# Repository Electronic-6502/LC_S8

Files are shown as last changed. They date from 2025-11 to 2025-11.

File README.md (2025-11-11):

# What is this ?
LC_S8 is a Open Source LC meter
can Measure Frequency, Capacitance (and ESR) and Inductance

# 3D PreView
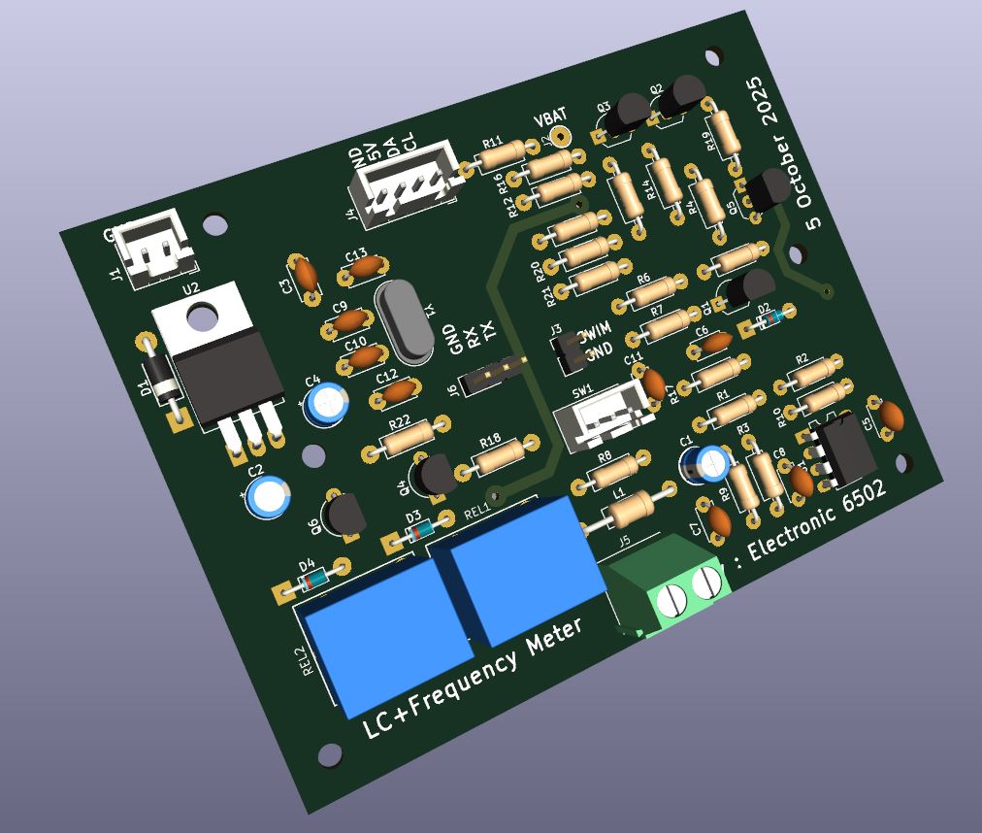
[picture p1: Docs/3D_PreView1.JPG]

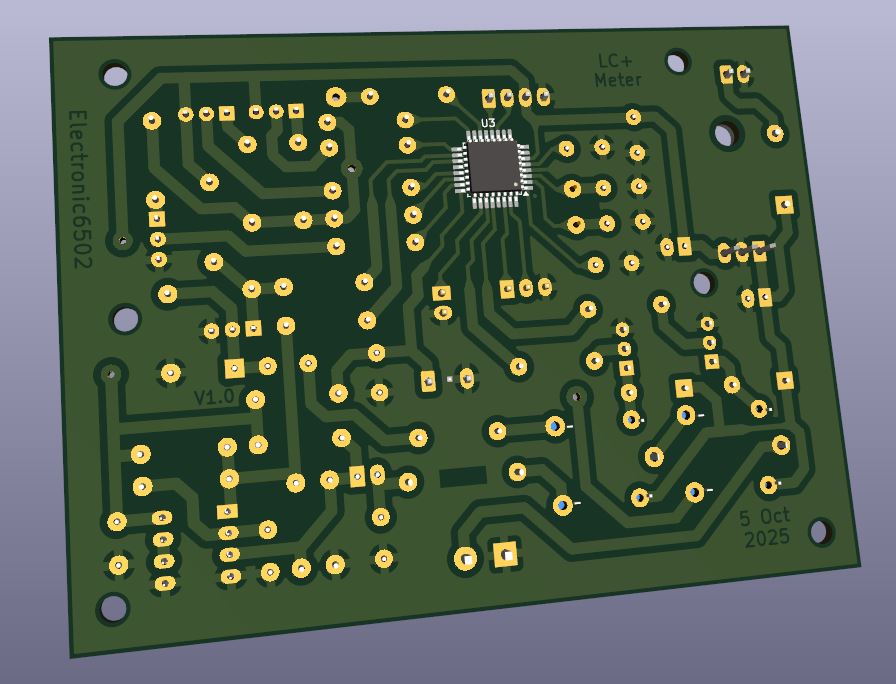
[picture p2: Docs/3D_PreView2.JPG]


# Specifications
 ## Power Supply
 - Voltage : 9-12V (9V Recommended)
 - Current : 150mA Max

 ## Frequency Meter :
 - Frequency Range : 2Hz - 8MHz
 - Resolution : 1Hz for F<10kHz and 0.01kHz for F>=10kHz
 - Tolerence : 0.1% Max
 - minimum Signal Amplitude : 0.2Vrms for F>50Hz and 1Vrms for F<=50Hz
 - Maximum Amplitude : 50Vpp

 ## Capacitance Meter :
 - Capacitance Range : 5pF to 50mF
 - Tolerence : 5% Max
 - ESR Range : 0.01Ω to 100Ω
 - Measure Stand-Alone Resistor : YES
 - Injected Input Voltage Range : -6V to +6V

 ## Inductance Meter 
 - Inductance Range : 0.01uH to 999H
 - Tolerence : 5% Max (NOT Guaranted !)

# File Structure 
 ## Docs
  misc Documents Like Components List (now only in Persian Language)

 ## Source
  Source Code with Libraries in C Language
 
 ## Hardware
  Schematic and PCB Files
 
 ## HEX_Build
  Ready-to-Program HEX File for Microcontroller

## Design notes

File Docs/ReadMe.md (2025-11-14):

There are 3 XH connector and 1 KF128 terminal on the PCB.
J1 (KF128) is used for power supply. It is suggested to use Litium-ion battery with a boost converter for power supply. Using adapter for power supply, could lead to instability in measuring capacitance operation.
`J4` connector is connected to `PCF8574` module (in the back 1602 LCD). Name of each pin is written beside.
`SW1` connector, connects to the push button. Important notice is middle pin is not used and it should be removed (with a plier) from male connector.
`J5` terminal is connected to measuring probes.

# usage, calibration and first uses

This PCB have 3 modes for measuring:
- Frequency
- Capacitance
- Inductor

After turn on, the deafult mode is Frequency meter. with pressing button, it will go to next mode (Capacitor) and with another press it will go to next (Inductance) and this cycle will will continue.
If in either Capacitor or Inductor mode, if the button is hold for some seconds, PCB goes into calibration mode.

## Calibrating Capacitor Meter
Put the PCB into Capacitance mode. Press and hold the button for some seconds. When LCD is wiped out, you can release the button. the message `Short Probes and Press Button` will appear on the LCD which you should short-circuit the measuring probes and then press the button.
then `Open Probes and Press Button` message will appear which you have to separate the probes and press the buttom again. then the message `Calibration Success` is shown and it means the successfull calibration.

## Calibrating Inductor Meter
Put the PCB into Capacitance mode and short circuit the probes.
Then press and hold the button, untill the message `Calibrated` is shown which means successfully calibrated.

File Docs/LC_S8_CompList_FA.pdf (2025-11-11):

لیست قطعات پروژه LC متر
LC-S8
بروزرسانی : 20 آبان 1404

مقاومت ها:
مرجع مقدار توان تعداد
اهم 100 R15, R19

1/4 وات
)0.25W(

2
3 | 1K | R2, R6, R7 R12, R18, R21, R22
4 | 4.7K
R1, 3, 4, 8, 9, 11,
13, 14, 16, 17
10 | 10K
3 | 1M | R5, R10, R20

خازن ها :
مرجع ظرفیت ولتاژ نوع تعداد
2 | | عدسی | | 25-50V | 15-20pF | C9, C10
1 | MKT-NP0-C0G 50-250V | 4.7nF | C7
2 | الیر | مولتی- | عدسی | 25-50V | 10nF | C11, C12
4 | الیر | مولتی- | عدسی | 25-50V | 100nF | C3, C5, C6, C8
13C uF1 V25-50 عدسی-مولتی الیر 1
1 | الکترولیت | 25-63V | 10uF | C1
2 | پلیمری | - | الکترولیت | 16-25V | 100uF | C2, C4

سلف :
مرجع مقدار توان نوع تعداد
1 | Axial- | مقاومتی | 0.5-1W | 100uH | L1
| | | | page 1/2

دیود ها :
مرجع مدل / نام تعداد
1 | 1N5817 - 1N5819 | D1
3 | 1N4148 | D2, D3, D4
| ترانزیستور ها:
مرجع مدل / نام تعداد
1 | BC547 | Q1
1 | BC557 | Q2
1 | BC327 | Q3
3 | BC337 | Q4, Q5, Q6

آیسی و میکروکنترلر ها:
مرجع مدل / نام تعداد
1 | LM393 - KA393 | U1
1 | 7805 | U2
| | U3

STM8S003K3
or
STM8S103K3

1

سایر :
مرجع نام قطعه تعداد
1 | 2x16 | کاراکتری | LCD | -
- ماژول 8574PCF 1
2REL 1,REL رله 12 ولت پکیج 78T( بچه میلون( 2 1SW شستی فشاری 1
کانکتور XH نری 2و3و4 پین به همراه مادگی سیم دار، هر کدام 1 عدد

نکته : قطعاتی که با رنگ سبز مشخص شده اند ، به معنی توصیه شده با عملکرد / طول عمر بهتر هستند.

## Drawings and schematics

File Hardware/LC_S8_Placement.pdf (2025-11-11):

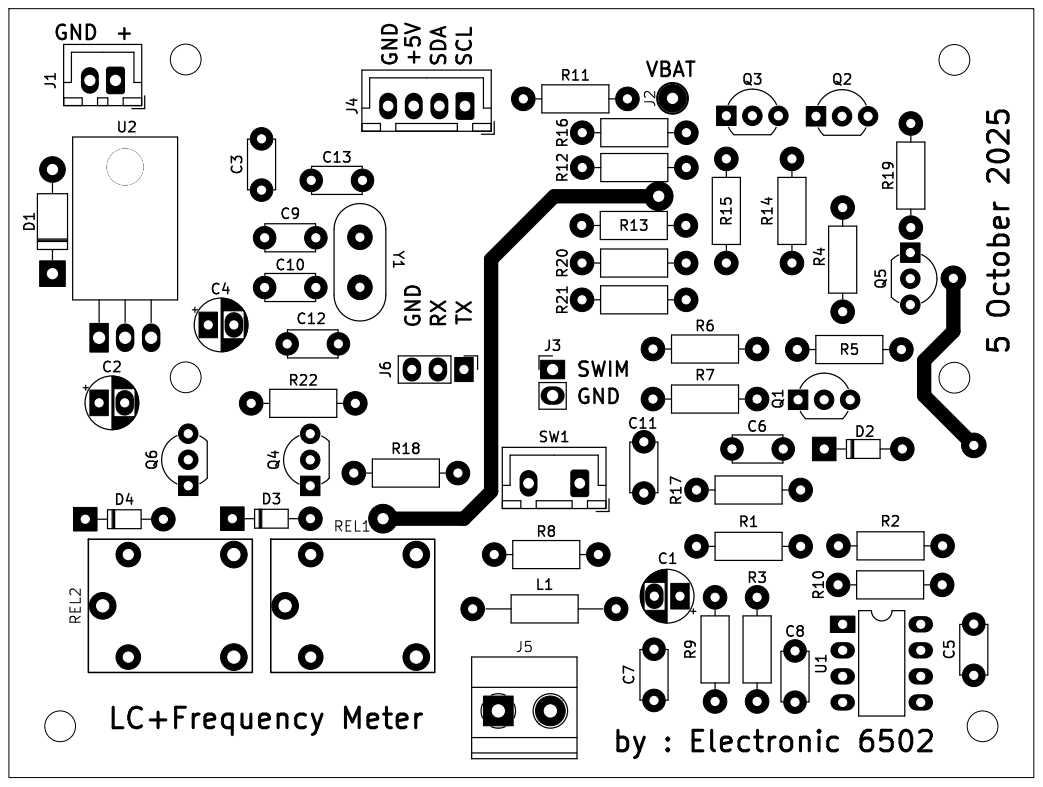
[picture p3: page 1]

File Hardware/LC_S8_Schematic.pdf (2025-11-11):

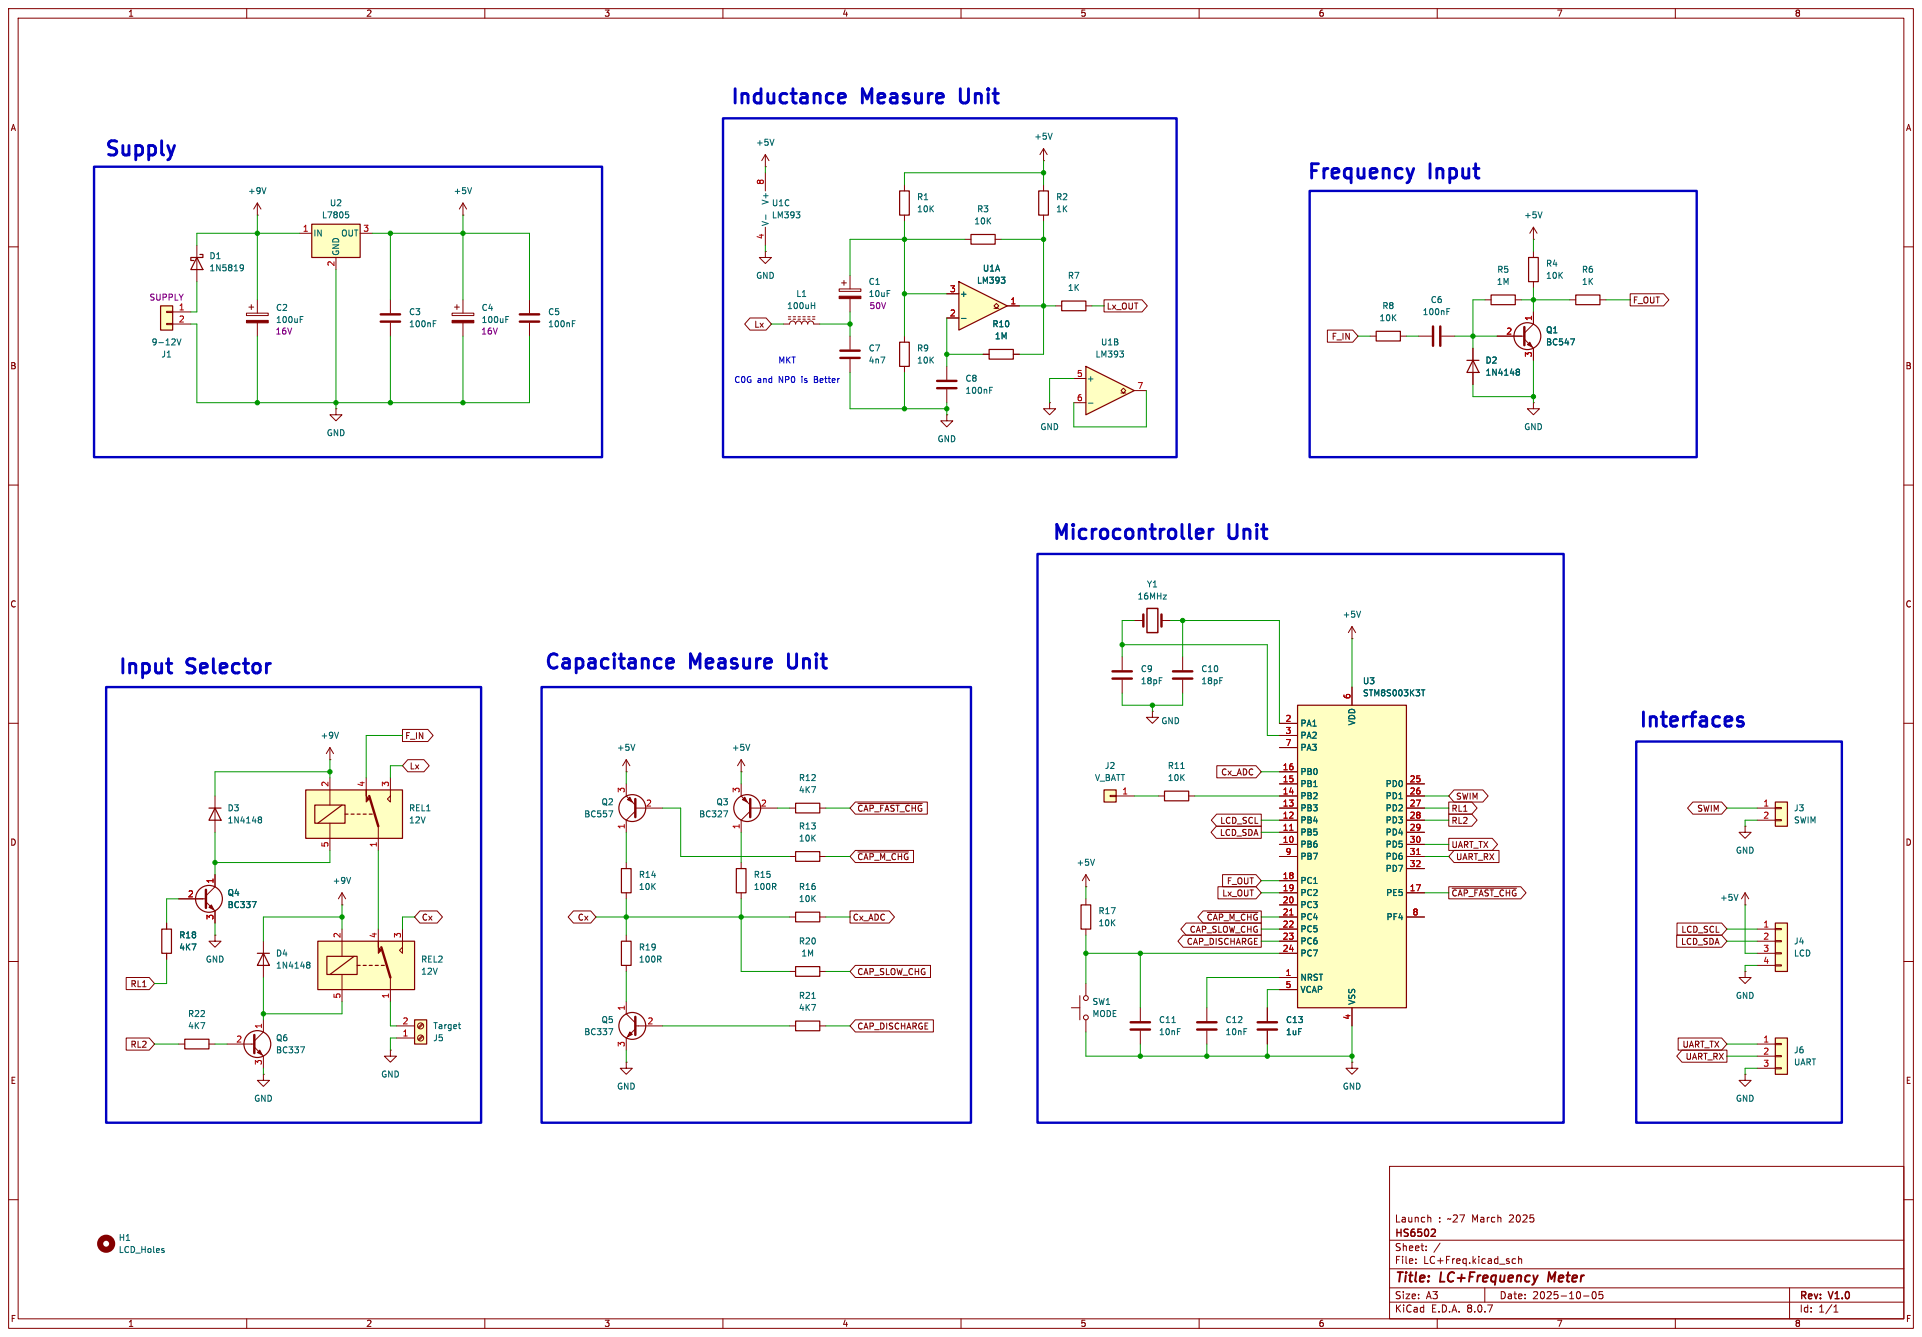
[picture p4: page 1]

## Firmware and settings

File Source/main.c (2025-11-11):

/**
 * @file    main.c
 * @author  Electronic6502
 * @version V1.0
 * @date    8 Oct 2025
 * @brief   LCR1 Source File
 */
/* Toolchain : SDCC */
#include <string.h>
#include "3rd_Lib/stm8s.h"
#include "periph_and_misc.h"
#include "LCD_1602.h"

#define VERSION         "V1.0"

#define C9_CAP_VAL      0.0000000047f          /* Value of C9 on PCB in Farad */ // 4.45nf mog

#define R19_L_VAL       1000000.0f              /* Capacitor Charge Resistors */
#define R12_M_VAL       10000.0f
#define R13_H_VAL       100.0f

uint8_t Crystal_Error_Flag = 0;
uint8_t Unit_String [4];
const uint8_t Empty[] = {"          "};         /* 10x Empty Character */
volatile uint8_t GotoNextMode = 0;
volatile uint8_t Button_Hold_Cnt = 0;
volatile uint16_t TIM1_OVF_Count = 0;
volatile uint16_t TIM2_OVF_Count = 0;

void Boot_Messages (void){
    static float VBAT;
    LCD_GotoXY (5,0);
    LCD_PutString ("LC-S8\n");
    LCD_GotoXY (5,1);
    LCD_PutString (VERSION);
    Delay_ms (2000);
    LCD_Clear ();
    LCD_GotoXY (6,0);
    LCD_PutString ("by:\n Electronic-6502");
    Delay_ms (2000);
    LCD_Clear ();
    LCD_PutString ("Battery Voltage\n");
    VBAT = (ADC_Read(VBAT_ADC) / 1023.0f) * 5.0f;       /* Read Battery Voltage */
    Print_Float (VBAT);
    LCD_PutChar ('V');
    Delay_ms (1800);
    if (Crystal_Error_Flag){
        LCD_Clear ();
        LCD_GotoXY (4,0);
        LCD_PutString ("Warning! \n Crystal Error!");
        Delay_ms (5000);
    }
    LCD_Clear ();
}

void ModeConfig (uint8_t Mode){
    Delay_ms (150);                                             /* Delay Needed to Debouncing Button */
    GotoNextMode = 0;
    LCD_Clear ();
    if (Mode == MODE_Frequency){   
        PinLow (REL_PORT, REL1_PIN);                            /* Switch Relay1 to NC */
        PinLow (REL_PORT, REL2_PIN);                            /* Switch Relay2 to NC */
        LCD_PutString ("Frequency:");
    }
    else if (Mode == MODE_Capacitance){
        PinHigh (REL_PORT, REL2_PIN);                           /* Switch Relay2 to NO */
        LCD_PutString ("CAP:"); 
        LCD_GotoXY (0,1);                                       /* Goto Next Line */
        LCD_PutString ("ESR:");                                   
    }
    else {                                                      /* Inductance Meter */
        PinLow (REL_PORT, REL2_PIN);
        PinHigh (REL_PORT, REL1_PIN);                           /* Switch Relay1 to NO */
        LCD_PutString ("Inductance:");
    }
    TIM1_Config_for (Mode);
}

void FrequencyMeter (void){
    float Freq;
    ModeConfig (MODE_Frequency);
    while (GotoNextMode == 0){
        Freq = TIM1_PulseCounter (1000);
        LCD_GotoXY (0,1); 
        LCD_PutString (Empty);
        LCD_GotoXY (0,1);
        if (Freq < 10000.0f){
            strcpy (Unit_String, "Hz");
            Print_Number (Freq);
        } 
        else{
            strcpy (Unit_String, "kHz");
            Freq /= 1000.0f;
            Print_Float (Freq);
        }
        LCD_PutString (Unit_String);
    }
}

void Capacitor_Discharge (void){
    PinHigh (CAP_PORT, CAP_DISCHG_PIN);
    while (ADC_Read(CAP_ADC) > 1);                         /* Wait for Discharge Capacitor */
    Delay_ms (10);
    PinLow (CAP_PORT, CAP_DISCHG_PIN);    
}

uint8_t Calibrate = 0;
    
float Measure_ESR (void){
    uint16_t ADC_Val, i;
    float ESR, ESR_ZERO, Volt, DurPulse, AfterPulse;        /* ESR Meter Variables */
    ESR_ZERO = EEPROM_Read_Float (EEP_ESR_ZERO_ADDR);    
    AfterPulse = 0.0f;
    DurPulse   = 0.0f;
    PinOutput (CAP_PORT, CAP_CHG_LOW_PIN);
    PinLow (CAP_PORT, CAP_CHG_LOW_PIN);                 /* Pull Down ADC with 1MΩ Resistor */
    for (i=0; i<256; i++){
        PinHigh (CAP_PORT, CAP_DISCHG_PIN);             /* Discharge Capacitor */
        Delay_us (600);
        PinLow (CAP_PORT, CAP_DISCHG_PIN);              /* Stop Discharging */        
        PinLow (CAP_HIGH_PORT, CAP_CHG_HIGH_PIN);       /* Start 50mA Pulse */
        //Delay_us (2);
        ADC_Val = ADC_Read (CAP_ADC);                   /* Read ADC During Pulse */
        PinHigh (CAP_HIGH_PORT, CAP_CHG_HIGH_PIN);      /* Stop 50mA Pulse */
        DurPulse += ADC_Val;
        Delay_us (50);                                  /* wait for Overhead Voltage drop */
        AfterPulse += ADC_Read (CAP_ADC);
    }
    PinInput (CAP_PORT, CAP_CHG_LOW_PIN);               /* Disable Pull Down */
    DurPulse = DurPulse - AfterPulse;
    Volt = (VREF * DurPulse) / 261888.0f;               /* Measure Voltage */
    ESR = R13_H_VAL / ((VREF / Volt) - 1.0f);
    if (Calibrate){
        ESR_ZERO = ESR;
        EEPROM_Save_Float (ESR_ZERO, EEP_ESR_ZERO_ADDR);
        LCD_Clear ();
        LCD_PutString ("Open Probes and\n Press Button");
        while (ReadPin (BUTTON_PORT, BUTTON_PIN));
        Delay_ms (500);
    }
    ESR = (ESR - ESR_ZERO) - 0.05f;       /* ESR minus Offset Resistance and Capacitor Charge Voltage */
    return ESR;
}

void CapacitorMeter (void){
    static float CAP, CAP_ZERO, ChargeTime, ESR;
    CAP_ZERO = EEPROM_Read_Float (EEP_CAP_ZERO_ADDR);
    RESTART_CAP_METER :
    ModeConfig (MODE_Capacitance);    
    while (GotoNextMode == 0){
        Capacitor_Discharge ();
        if (ReadPin(BUTTON_PORT, BUTTON_PIN) == 0){
            Button_Hold_Cnt++;
            if(Button_Hold_Cnt > 5) Calibrate = 1;
        }
        if (Calibrate){
            LCD_Clear ();
            while (ReadPin (BUTTON_PORT, BUTTON_PIN) == 0); /* Wait for Button Release */
            LCD_PutString ("Short Probes and\n Press Button");
            Delay_ms (500);
            while (ReadPin (BUTTON_PORT, BUTTON_PIN));      /* Wait for Press Button */
            Delay_ms (500);
        }
        CAP = 0.0f;
        ADC_Config ();                                      /* ADC in Single Conversion Mode */
        ESR = Measure_ESR ();
        ADC1->CR1 |= ADC1_CR1_CONT;                         /* ADC in Continuous Conversion Mode */
        ADC1->CR1 |= ADC1_CR1_ADON;                         /* Start ADC Conversion */
        TIM1_ResetCounter ();
        PinLow (CAP_HIGH_PORT, CAP_CHG_HIGH_PIN);     /* Charge Capacitor with ~50mA (for Short Check) */
        Delay_ms (50);
        PinHigh (CAP_HIGH_PORT, CAP_CHG_HIGH_PIN);          /* Stop Charging */
        Delay_ms (1);
        if (ADC_Read_CONT() > 1){                        /* Capacitor have Voltage, Not Shorted */
            Capacitor_Discharge ();
            PinLow (CAP_HIGH_PORT, CAP_CHG_HIGH_PIN);
            TIM1->CR1 |= TIM1_CR1_CEN;                          /* Enable Counter */
            while (ADC_Read_CONT() < 646);
            TIM1->CR1 &= ~TIM1_CR1_CEN;                         /* Disable Counter */
            PinHigh (CAP_HIGH_PORT, CAP_CHG_HIGH_PIN);
            ChargeTime = TIM1_ReadCount();                      /* Read Capacitor RC Time in uS */
            CAP = (ChargeTime / R13_H_VAL);                     /* Measure Capacitance in uF */               

            if (ChargeTime < 3000.0f){                          /* Capacitor between 300nF and 30uF */
                TIM1_ResetCounter ();
                Capacitor_Discharge ();
                PinLow (CAP_PORT, CAP_CHG_MED_PIN);             /* Charge Capacitor with ~500uA */
                TIM1->CR1 |= TIM1_CR1_CEN;
                while (ADC_Read_CONT() < 646);
                TIM1->CR1 &= ~TIM1_CR1_CEN;
                PinHigh (CAP_PORT, CAP_CHG_MED_PIN);    
                ChargeTime = TIM1_ReadCount(); 
                CAP = (ChargeTime / R12_M_VAL);                 /* Measure Capacitance in uF */           
            }           
            if (ChargeTime < 3000.0f){                          /* Capacitor Smaller than 300nF */
                TIM1_ResetCounter ();
                Capacitor_Discharge ();
                PinOutput (CAP_PORT, CAP_CHG_LOW_PIN);
                PinHigh (CAP_PORT, CAP_CHG_LOW_PIN);
                TIM1->CR1 |= TIM1_CR1_CEN;
                while (ADC_Read_CONT() < 646);
                TIM1->CR1 &= ~TIM1_CR1_CEN;
                PinInput (CAP_PORT, CAP_CHG_LOW_PIN);
                PinLow (CAP_PORT, CAP_CHG_LOW_PIN);    
                ChargeTime = TIM1_ReadCount(); 
                CAP = (ChargeTime / R19_L_VAL);                 /* Measure Capacitance in uF */                 
            }                                           
            LCD_GotoXY (4,0);
            LCD_PutString (Empty);
            LCD_GotoXY (4,0);
            if (CAP < 0.001f){                                  /* Capacitor Smaller than 1nF */
                Print_Number ((CAP - CAP_ZERO) * 1000000.0f);
                strcpy (Unit_String, "pF");
            }
            else if ((CAP >= 0.001f) && (CAP < 1.0f)){          /* Capacitor between 1nF and 1uF */
                Print_Float ((CAP - CAP_ZERO) * 1000.0f);       /* CAP_ZERO = Parasitic Capacitor */
                strcpy (Unit_String, "nF");
            }
            else if ((CAP >= 1.0f) && (CAP < 10000.0f)){        /* Capacitor between 1uF and 10mF */
                Print_Float (CAP);
                strcpy (Unit_String, "uF");
            }
            else {                                              /* Capacitor Larger than 10mF */
                Print_Float (CAP / 1000.0f);
                strcpy (Unit_String, "mF");
            }
        }
        else {
            LCD_GotoXY (4,0);
            LCD_PutString (Empty);
            LCD_GotoXY (4,0);
            strcpy (Unit_String, "---");                 /* Shorted Capacitor or Discreate Resistor */
            ESR += 0.05f;                                       
        }
        LCD_PutString (Unit_String);
        LCD_GotoXY (4,1);
        LCD_PutString (Empty);
        LCD_GotoXY (4,1);
        if ((ESR < 100.0f) && ((CAP == 0.0f) || (CAP > 1.0f))){ /* show ESR if Lower than 100 Ω */
            Print_Float (ESR);
            LCD_PutChar (0xF4);                                 /* Display ohm (Ω) Symbol */              
        }
        else {
            LCD_PutString ("---");
        }
/*=========================== Capacitance Meter Calibration ===========================*/
        if (Calibrate){
            CAP_ZERO = CAP;
            EEPROM_Save_Float (CAP_ZERO, EEP_CAP_ZERO_ADDR);
            LCD_Clear ();
            LCD_PutString ("  Calibration \n   Success !!  ");
            Delay_ms (3000);
            Calibrate = 0;
            goto RESTART_CAP_METER;
        }

    }
}

void InductanceMeter (void){
    float L1, Lx, CurrentFreq, Freq0;
    L1 = EEPROM_Read_Float (EEP_L1_ADDR);
    Freq0 = EEPROM_Read_Float (EEP_FREQ0_ADDR);
    RESTART_IND_METER :
    ModeConfig (MODE_Inductance);
    while (GotoNextMode == 0){
        CurrentFreq = TIM1_PulseCounter (50);
        if ((CurrentFreq > 3.0f) && (CurrentFreq < 150.0f)){    /* Choice Best Gate Time */
            CurrentFreq = TIM1_PulseCounter (1000);
        }
        else{
            CurrentFreq = TIM1_PulseCounter (400);
            CurrentFreq *= 2.5f;
        }
        Lx = (((Freq0 * Freq0)/(CurrentFreq * CurrentFreq))-1.0f ) * L1;
        LCD_GotoXY (0,1);
        LCD_PutString (Empty);
        LCD_GotoXY (0,1);        
        if (Lx < 0.001){
            strcpy (Unit_String, "uH");
            Print_Float (Lx * 1000000.0f);
        }
        else if ((Lx >= 0.001f) && (Lx < 1.0f)){
            strcpy (Unit_String, "mH");
            Print_Float (Lx * 1000.0f);
        }
        else if ((Lx >= 1.0f) && (Lx < 100.0f)){
            strcpy (Unit_String, "H");
            Print_Float (Lx);
        }
        else {
            strcpy (Unit_String, "---");
        }
        LCD_PutString (Unit_String);
/*======================================== Calibration ========================================*/
        if (ReadPin (BUTTON_PORT, BUTTON_PIN) == 0){
            if (Button_Hold_Cnt > 5){                 
                L1 = 1.0f / (PI_POW2_4x * (CurrentFreq * CurrentFreq) * C9_CAP_VAL);
                Freq0 = CurrentFreq;
                EEPROM_Save_Float (L1, EEP_L1_ADDR);
                EEPROM_Save_Float (Freq0, EEP_FREQ0_ADDR);
                LCD_GotoXY (0,1);
                LCD_PutString ("Calibrated!!");
                Delay_ms (3000);
                goto RESTART_IND_METER;
            }
            Button_Hold_Cnt++;
        }
    }
}

void GPIOC_ISR (void)__interrupt(5){            /* GPIOC Interrupt Vector (Button Detection) */
    if (Button_Hold_Cnt < 2){
        GotoNextMode = 1;
    }
    Button_Hold_Cnt = 0;
}

void Timer1_Overflow (void)__interrupt(11){     /* Timer1 Overflow Vector */
    TIM1_OVF_Count++;
    TIM1->SR1   = 0x00;
}

void Timer2_Overflow (void)__interrupt(13){
    TIM2_OVF_Count++;
    TIM2->SR1   = 0x00;                     /* Clear Update Flag */
}

void main (void){
    disableInterrupts();                    /* Global Disable Interrupts */
    GPIO_Config ();
    TIM2_Config_for_Delay ();
    enableInterrupts();                     /* Global Enable Interrupts */
    Crystal_Error_Flag = Clock_Config ();
    ADC_Config ();
    LCD_Init ();
    Boot_Messages ();
    while(1){
        FrequencyMeter ();
        CapacitorMeter ();
        InductanceMeter ();
    }
}

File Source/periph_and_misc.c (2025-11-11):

/**
 * @file    periph_and_misc.c
 * @author  Electronic6502
 * @version V1.0
 * @date    9 Oct 2025
 * @brief   STM8 Microcontroller Peripherals Configuration and Some Misc Functions.
 */

#include "periph_and_misc.h"

extern volatile uint16_t TIM2_OVF_Count;
extern volatile uint16_t TIM1_OVF_Count;

void GPIO_Config (void){
    GPIOA->DDR = 0x00;                  /* GPIOA All pins as Input */
    GPIOC->DDR = 0x70;                  /* GPIOC pin 4,5,6 as OUTPUT */ 
    GPIOD->DDR = 0x2C;                  /* GPIOD pin 2,3,5 as OUTPUT */
    GPIOE->DDR = 0x20;                  /* GPIOE pin 5 as OUTPUT */

    GPIOC->CR1 = 0x70;                  /* GPIOC pin 4,5,6 Mode Push-Pull */
    GPIOD->CR1 = 0x2C;                  /* GPIOD pin 2,3,5 Mode Push-Pull */
    GPIOE->CR1 = 0x20;                  /* GPIOE pin 5 Mode Push-Pull */

    GPIOC->CR2 = 0x80;                  /* GPIOC pin 7 Enable Interrupt */
    EXTI->CR1  = 0x10;                  /* GPIOC Interrupt on Rising Edge */

    GPIOC->ODR = 0x10;                  /* GPIOC pin 4 set to High */
    GPIOE->ODR = 0x20;                  /* GPIOE pin 5 set to High */
}

uint8_t Clock_Config (void){
    uint8_t Error_Flag = 0;
	CLK->CKDIVR = 0x00;				    /* Run CPU and Peripherals at 16MHz */		            
	CLK->ECKR = 0x01;				    /* Enable External Crystal Clock Source */
	CLK->SWR = 0xB4;				    /* Select External Crystal at Master Clock */
    Delay_ms (10);                      /* Delay needed for Stablization External Crystal */
	if(CLK->SWCR & 0x08){			    /* if External Crystal Available */
		CLK->SWCR &= 0xF7;			    /* Clear SWIF Flag */			
		CLK->SWCR |= 0x02;			    /* Switch Master Clock to External Crystal */
	}
	else{							    /* if External Crystal UnAvailable, Switch Back to HSI */
		CLK->SWR = 0xE1;
		CLK->ECKR = 0x00;
        Error_Flag = 1;                 /* Set External Crystal Error Flag */
	}    
    return Error_Flag;
}

void ADC_Config (void){
    ADC1->CR1   = 0x10;                                 /* ADC Clock = fMaster / 3 */
    ADC1->CR2   = ADC1_CR2_ALIGN;                       /* ADC Data in Right Alignment Mode */
    ADC1->TDRL  = (1 << VBAT_ADC) | (1 << CAP_ADC);     /* Disable ADC Channel Schemitt Trigger */
    ADC1->CR1   |= ADC1_CR1_ADON;                       /* Wakeup ADC from Sleep */
}

static uint16_t Result = 1;                             /* Static Variable for Fastest Access Speed */

inline uint16_t ADC_Read_CONT (void){
    while ((ADC1->CSR & ADC1_CSR_EOC) == 0);
    Result  = ADC1->DRL;
    Result |= (ADC1->DRH << 8);
    ADC1->CSR = 0;
    return Result;
}

uint16_t ADC_Read (uint8_t Channel){
    ADC1->CSR  = Channel;
    ADC1->CR1 |= ADC1_CR1_ADON;                   /* Start ADC Conversion */
    while ((ADC1->CSR & ADC1_CSR_EOC) == 0);        /* Wait for End Conversion */
    Result  = ADC1->DRL;
    Result |= (ADC1->DRH << 8); 
    ADC1->CSR = 0;                                  /* Clear EOC Flag and Select Channel 0 */
    return Result;
}

void TIM1_Config_for (uint8_t Mode){
    TIM1->CR1   = 0x00;                 /* Disable Timer Counter */
    TIM1->IER   = 0x00;                 /* Disable Timer1 Interrupts */
    TIM1->CCER1 = 0x00;                 /* Disable Capture */
    TIM1->ARRH  = 0xFF;
    TIM1->ARRL  = 0xFF;                 /* Set Auto Reload Value to 65535 */
    TIM1->PSCRH = 0;
    if (Mode == MODE_Frequency){
        TIM1->CCMR1 = 0x01;             /* Timer1 Channel 1 Selected as Capture Input */
        TIM1->CCER1 = TIM1_CCER1_CC1E;  /* Timer1 Capture Enabled, Sens = Rising Edge */
        TIM1->SMCR  = 0x57;             /* Timer1 in External Clock Mode with Channel 1 */
        TIM1->PSCRL = 0x00;             /* Timer1 Clock Prescaler = 1 */
    }
    else if (Mode == MODE_Inductance){
        TIM1->CCMR1 = 0x02;             /* Timer1 Channel 2 Selected as Capture Input */
        TIM1->CCER1 = TIM1_CCER1_CC1E;  /* Timer1 Capture Enabled, Sens = Rising Edge */
        TIM1->SMCR  = 0x67;             /* Timer1 in External Clock Mode with Channel 2 */
        TIM1->PSCRL = 0x00;             /* Timer1 Clock Prescaler = 1 */
    }
    else if (Mode == MODE_Capacitance){
        TIM1->CCMR1 = 0x00;
        TIM1->CCER1 = 0x00;
        TIM1->SMCR  = 0x00;             /* Timer1 Set to Normal Mode (Internal Clock) */
        TIM1->PSCRL = 16;               /* Timer1 Clock = Fmaster / 16 */
    }
    TIM1->EGR   = TIM1_EGR_UG;          /* Update Registers for Take Prescaler */
    TIM1->IER   = TIM1_IER_UIE;         /* Enable Overflow Interrupt */
}

void TIM2_Config_for_Delay (void){
    TIM2->PSCR  = 4;                    /* Timer2 Clock = Fmaster / (2^4) */
    TIM2->ARRH  = (999 >> 8);           
    TIM2->ARRL  = (999 & 0xFF);         /* Set Overflow Value to 999 */
    TIM2->EGR   = TIM2_EGR_UG;          /* Generate Update Event for Take Prescaler */
    TIM2->IER   = TIM2_IER_UIE;         /* Enable Overflow Interrupt */
}

void Delay_us (uint16_t us){
    uint16_t tick = 0;
    TIM2->CNTRH = 0x00;
    TIM2->CNTRL = 0x00;                 /* Reset Counter Register */
    TIM2->CR1   = TIM2_CR1_CEN;         /* Enable Timer Counter */
    while (tick < us){
        tick  = (TIM2->CNTRH << 8);
        tick |= TIM2->CNTRL;
    }
    TIM2->CR1   = 0x00;                 /* Disable Timer Counter */
}

void Delay_ms (uint16_t ms){
    TIM2_OVF_Count = 0;
    TIM2->CNTRH = 0x00;
    TIM2->CNTRL = 0x00;                 /* Clear Counter Register */
    TIM2->CR1   = TIM2_CR1_CEN;         /* Enable Timer Counter */
    while (TIM2_OVF_Count < ms);
    TIM2->CR1   = 0x00;                 /* Disable Timer Counter */
}

float EEPROM_Read_Float (uint8_t Address){
    return (*(volatile float*)(0x4000 + Address));
}

void EEPROM_Save_Float (float Value, uint8_t Address){
    FLASH->DUKR  = 0xAE;
    FLASH->DUKR  = 0x56;                 /* Disable EEPROM Write Protect */
    (*(volatile float*)(0x4000 + Address)) = Value;
    FLASH->IAPSR = 0x00;                 /* Enable EEPROM Write Protect */
}

void TIM1_ResetCounter (void){
    TIM1->CR1   = 0;
    TIM1->CNTRH = 0;
    TIM1->CNTRL = 0;
    TIM1_OVF_Count = 0;
}

float TIM1_ReadCount (void){
    uint16_t tmp = 0;
    float Pulses;
    tmp = (TIM1->CNTRH << 8);
    tmp |= TIM1->CNTRL;
    Pulses = tmp + ((float)TIM1_OVF_Count * 65536);
    return Pulses;
}

float TIM1_PulseCounter (uint16_t GateTime_ms){
    TIM1_ResetCounter ();
    TIM1->CR1 |= TIM1_CR1_CEN;
    Delay_ms (GateTime_ms);
    TIM1->CR1 &= ~TIM1_CR1_CEN;
    return TIM1_ReadCount();
}

/*===================================== Misc Functions =====================================*/
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

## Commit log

2025-11-11 First Commit
    Date : 11 Sep 2025
    [LC_S8.PcbDoc]
2025-11-11 Add Board 3D View
    11 Sep 2025
